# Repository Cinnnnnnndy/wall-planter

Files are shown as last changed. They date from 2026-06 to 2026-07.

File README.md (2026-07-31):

# Wall Planter — 参数化墙面种植单元

用 OpenSCAD 做的**参数化、可拼接、可 3D 打印**的单盆位墙面种植单元。对标实物:斜置花盆阵列 + 逐层滴灌 + 底部储水 + 四向堆叠拼接。面向**拓竹 P2S**(有效 256³,按 ≤240mm/轴 设计)。

## 正确形态
单元由**三个部件**组成(不是"实心块挖洞"):

1. **薄背板(panel)** — 竖直基准面,贴墙/堆叠用。
2. **前伸斜置中空杯体(cup)** — 有壁厚的圆台管,从背板向前上方斜伸(~40°);宽端开口在前上方放可拆锥形花盆,窄端平切坐在储水盒上。
3. **底部储水盒(reservoir)** — 封闭浅盒 + 前唇 + 溢流标管;杯底排水进盒,超水位经标管穿底滴到下层,底层塞橡胶塞。

## 当前文件
- **`filesv2/wall_planter_v4.scad`** — 当前基础(单元 164×183×191mm,三轴 ≤240,`Volumes=2`)。
- `filesv2/planter_v4.3mf` — 导出的可打印件(**推荐**,带 mm 单位,直接拖进拓竹 Bambu Studio / 其它切片软件)。
- `filesv2/planter_v4.stl` — 同一几何的 STL 版本(兼容老工具链)。
- `filesv2/PROMPT.md` — 几何形态描述 + 已完成/待办清单。
- `files/SPEC.md`、`files/CLAUDE.md` — 设计目标与建模迭代规范。
- `files/` 内为早期 v2 迭代(竖切开口版),供参考。

## 可调参数(在 .scad 顶部)
花盆尺寸 `pot_top_d / pot_bot_d / pot_height`、间隙 `fit_clear`、倾角 `tilt`、壁厚 `wall`、储水盒高 `res_h` / 水位 `water_h` / 前唇 `res_lip`、堆叠/横拼销径、透气孔等。

## 渲染 / 导出(OpenSCAD)
```bash
cd filesv2
# 立体预览
openscad --render -o v4_hero.png --colorscheme=Tomorrow \
  --imgsize=1000,820 --camera=82,150,150,62,0,225,720 wall_planter_v4.scad
# 导出 3MF(出图确认后,推荐)
openscad --render -o planter_v4.3mf -D 'dev=false' wall_planter_v4.scad
# 导出 STL(同一几何,兼容用)
openscad --render -o planter_v4.stl -D 'dev=false' wall_planter_v4.scad
```
开发期保持 `dev=true`(低精度快预览),导 STL 前用 `-D 'dev=false'` 提精度。

## 打印建议
建议**背板朝下平躺**打印(杯口朝上),基本免支撑;默认壁厚 3mm。

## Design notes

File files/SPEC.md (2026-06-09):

# SPEC — 我的设计目标(改模型前先读这个)

## 1. 打印机(必填,决定是否分块)
- 有效打印尺寸 X × Y × Z = **256 × 256 × 256** mm(拓竹 Bambu Lab P2S)
- 机型/喷嘴:**P2S / 0.4mm**
- 材料:待定(室内建议 PLA,室外建议 PETG/ASA)

## 2. 安装方式(三选一)
- [ ] 贴墙挂(需挂耳/锁孔或法式斜挂)
- [ ] 独立隔断(需底座脚,可能做双面花盆)
- [x] **仅堆叠**(无墙面安装件;但保留燕尾+定位销,单元间四向拼接)

## 3. 花盆形式
- 用户**自带实物锥形盆**,模块只做**承接斜插的盆座(socket)**,盆可单独取放/换盆。
  盆座按实测盆型 + 间隙做成锥台腔,不另打印花盆。

## 4. 防水要求(二选一)
- [x] **仅逐层淌水**,底层加堵塞别滴地上(当前默认)
- [ ] 真·密封储水

## 目标参数(已按用户实测盆填好)
| 参数 | 含义 | 值 |
|---|---|---|
| pot_top_d | 盆口外径(实测) | **131.2** |
| pot_bot_d | 盆底外径(实测) | **93.2** |
| pot_height | 盆高(实测) | **148** |
| pot_fit | 落盆间隙(直径上加) | **3.0(单边 1.5,已确认)** |
| pot_tilt | 杯腔倾角(度, 与水平) | **55(已确认, 更竖立贴参考图)** |
| cols | 每模块列数 | **1**(2 列=270mm 超 256,故单列) |
| rows | 每模块行数 | **1**(2 行=340mm 超 256,故单行) |
| gap_x | 花盆水平间距 | 9 |
| gap_z | 花盆行间距 | 12 |
| wall | 箱体壁厚 | 2.6 |
| reservoir | 底部储水层高 | 16 |

> 实际建模结果(已导 STL): 单元外形 = **155.4 × 191.0 × 215.5 mm**,三轴均 ≤240,P2S 单件可打;墙面靠多个单元堆叠+横拼。

## 已建模机制(planter_v2.stl, v4 斜切洁净开口, 2026-06-09)
- **开口沿花盆角度斜切**: 开口面 ⟂ 花盆轴线(=沿盆倾角), 是完整正圆、不被腔壁遮挡, 盆口平齐坐入。修复了 v3 在竖直面开圆被斜腔下壁遮挡的问题。
- **外壳=省料楔形**(非方盒): 侧剖面贴合花盆斜切, 顶/前随盆斜面、后矮竖壁、平底储水, 沿宽度拉伸→左右面平整可横拼。
- 腔体: 圆台(宽端 134.2 朝开口 / 窄端 96.2 在后下),深 150,**倾角 55°(更竖立)**,单边间隙 1.5mm(直径 +3)。
- 灌溉: 盆底排水 → 最低处储水沟(深 12)→ **溢流标管(水位 8mm)** 超水位穿底滴下层;底层标管口塞橡胶塞(⌀9)。
- 透气: 开口后上沿 3 个 ⌀5 透气孔(穿顶斜面进腔)。
- 顶后沿半圆缺口(⌀26)。
- 拼接(仅堆叠/非承重): 顶销(立在后顶斜面)+底孔、右销+左孔, 销径 7, 间隙 0.3。
- 校验: CGAL Volumes=2(单一实体, 无封闭空腔), 腔体不穿底/不穿背, 水路连通。
- 待优化: 顶面是斜的, 上下堆叠靠斜面销+侧销定位(非全平面贴合); 如需更稳的堆叠面可后续加平台接口。

## 备注
- 落盆间隙: SPEC 表里 pot_fit=2.0,但本次按 PROMPT 的「单边 1.5(直径 +3)」建模。若实测偏松/偏紧,改 `fit_clear` 即可。
- 待用户实测花盆后可调:若盆口有外翻边/卡边,可加「开口挡土前唇」防下滑;倾角可在 25–30° 间微调改变进深。
- 拼接当前用定位销(非承重燕尾);若横排需承重再换燕尾。

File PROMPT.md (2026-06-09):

# PROMPT — 单盆位墙面种植单元(喂给 Claude Code)

> 用法:把本文件放进项目根目录,在 Claude Code 里说「读 CLAUDE.md、SPEC.md、PROMPT.md,按 PROMPT 改 wall_planter_v2.scad」。
> 以现有 `wall_planter_v2.scad` 为基础**改造**,不要从零重写。每改一处按 CLAUDE.md 的闭环渲染 PNG 并查看,几何确认后导 STL。

## 目标
做一个**参数化、可 3D 打印、可堆叠/横拼**的「单盆位」墙面种植单元。
单元本身是一个**斜置的花盆托座(箱体)**,里面**斜放一个可拆卸的锥形花盆**;
顶部加水后水经盆底排水孔进入箱体底部储水层,超过水位逐层往下淌。

## 剖面机制(逐元素,来自参考剖面图)
箱体为侧剖,背板在后(贴墙侧),整体结构:

- **斜置锥形花盆腔**:箱体内主腔是一个**向后下方倾斜**的圆台(锥形)空腔,用来容纳可拆花盆。开口朝**前上方**(植物从这里长出、土朝外不易撒),盆底(窄端)落在**后下方**。倾角约 25–30°(设为参数 `pot_tilt`)。
- **植物苗**:从开口长出,叶子向前外舒展——开口必须在前面板上完整露出(正圆/椭圆开口)。
- **土壤层**:花盆内的种植土,占据锥形腔大部分。
- **透气孔**:箱体**上部侧壁/背壁**靠近盆口根部区域开若干小孔,给根系透气。位置在开口上沿一圈。
- **排水孔**:花盆**最低点(后下方盆底)**有孔,水向下穿过箱体进入底部储水层。
- **储水层**:箱体**最底部**的浅腔,承接排水孔下来的水;侧/底有**溢流孔**,超过水位则向下一层单元淌(逐层灌溉)。
- **顶部缺口**:箱体顶后沿有一处半圆缺口(参考图可见),给上方堆叠单元的水路/盆口让位,并辅助透气。
- **底层堵塞**:最底层单元的溢流孔需可被堵塞(留一个可塞橡胶塞的孔即可,不必建塞子),避免水滴到地面。

## 硬约束
- **打印机**:拓竹 P2S,有效打印体积 256×256×256mm;实际按 **≤ 240mm/轴** 设计留余量(左前角有禁打区)。
- **单元尺寸**:因花盆较大,**单次只打 1 个盆位**(`cols=1, rows=1`)。单元三维都必须 ≤ 240mm。组墙靠物理堆叠+横拼,不在单件里做多盆。
- **安装**:仅堆叠(`仅堆叠`)。**不要**加挂墙件、不要加底座脚。只需上下/左右的**堆叠定位**(定位销+孔或浅榫),保证摞起来不滑。
- **灌溉**:逐层淌水(drip-through),**不做**密封储水。储水层只需承接+溢流到下层,允许 FDM 轻微渗水。
- **材料/壁厚**:默认壁厚 2.6mm;免支撑优先。

## 可拆花盆尺寸(托座腔体按此 + 间隙)
托座的锥形腔要能**放进**这个花盆(花盆另购或另打,本单元先做托座):
- 盆高:**148 mm**
- 上开口外径:**131.2 mm**
- 盆底外径:**93.2 mm**(上大下小的圆台)

腔体取**单边 ~1.5mm 间隙**(直径方向 +3mm):腔上口径 ≈ 134.2mm,腔底径 ≈ 96.2mm,腔深 ≈ 150mm。
OpenSCAD 用 `cylinder(h=pot_depth, d1=底径, d2=上口径)` 做圆台,**宽端(d2)在开口/前,窄端(d1)在后下**。

## 需要从 wall_planter_v2.scad 改的点
1. **花盆腔改为圆台(锥形)**:把原来直圆柱 cup 换成 `d1/d2` 圆台,宽端朝开口。新增参数:`pot_top_d=131.2`、`pot_bot_d=93.2`、`pot_height=148`、`fit_clear=1.5`。`pot_d` 用 `pot_top_d+2*fit_clear` 派生。
2. **网格降为 1×1**:`cols=1, rows=1`。校核单元 W/D/H 三维都 ≤ 240,`echo` 出来确认。
3. **保留并对齐**:前面板正圆开口(用腔上口径)、开口上沿一圈**透气孔**、盆底**排水孔**、底部**储水层 + 溢流孔**。
4. **堆叠定位**:顶/底定位销+孔保留;左右用浅榫或销做横拼定位(不需要承重燕尾,因为是堆叠)。
5. **底层堵塞孔**:溢流孔尺寸设成可塞标准橡胶塞(留参数 `plug_d`,默认 ~12mm),不建塞子本体。
6. **杯体不穿背**:沿用 `mod_d` 含 `pot_d/2*sin(pot_tilt)` 容差项的写法(见 CLAUDE.md 已知坑)。

## 验收清单(逐项渲图确认)
- [ ] 正前视图(`rz=180`):开口为完整圆台口,植物能从中长出;开口上沿有透气孔。
- [ ] 立体图:花盆腔明显向后下倾斜,盆底在后下方。
- [ ] 剖视/底视:盆底排水孔 → 底部储水层 → 溢流孔贯通。
- [ ] 背面干净,无杯体穿出。
- [ ] `echo` 的单元 W×D×H 三维均 ≤ 240mm。
- [ ] `Volumes` 为 2(单一实体)。
- [ ] 导出 STL 成功。

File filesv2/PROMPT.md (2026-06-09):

# PROMPT v2 — 单盆位墙面种植单元(修正几何形态后)

> 用法:把本文件 + wall_planter_v4.scad + CLAUDE.md + SPEC.md 放进项目根目录。
> **以 wall_planter_v4.scad 为当前基础继续改**(v3=正确形态, v4=加了封闭储水盒/前唇/横拼/透气)。每改一处按 CLAUDE.md 闭环渲图查看,过验收清单后导 STL。

## ⚠️ 最重要:整体形态(之前做成实心块挖洞是完全错的)
本单元**不是**"一个实心立方体在前面挖一个圆洞"。
正确形态由**三个独立部件拼成**,杯体是**露在外面、有壁厚的中空管**:

1. **背板(panel)**:一块**薄**竖直板(厚约 8mm),是贴墙/堆叠的基准面,占满单元的宽×高。
2. **前伸斜置中空杯体(cup)**:一个**圆台形的管**(有 ~3mm 壁厚),从背板**向前上方斜伸出来**(轴线高于水平约 40°)。
   - 它是**外圆台实体 − 内圆台空腔**得到的**管**,不是在实心块里挖的洞;杯壁外表面是可见的。
   - **宽端(开口)在前上方**,植物从这里长出、人从前上方往里看;**窄端(杯底)在后下方**,坐在储水盒上。
   - 杯底留 ~6mm 厚的**底**承托花盆,底上有**排水孔**。
3. **储水盒(reservoir)**:底部一个**浅盒**(高约 24mm),承接杯底排水;盒底有**溢流孔**通向下层(最底层塞橡胶塞)。

> 判断对错的最快方法:**侧视图**应看到「竖直背板 + 一个斜约 40° 伸出的杯子 + 底部一条横置浅盒」三段;**立体图**应看到杯子是**有壁厚的张口管**,而不是平面上一个洞。

## 剖面细节(逐元素,对应参考剖面图的红点标注)
- **植物苗**:从杯体前上方开口长出。
- **土壤层**:可拆花盆放在杯体内,占据锥形内腔。
- **透气孔**:背板上部开 1–2 个小孔(贴近杯体后上方根区),给根透气。
- **排水孔**:杯底最低点 → 穿到储水盒。
- **储水层**:底部储水盒,承水;**溢流孔**在盒底,超过水位往下层淌(逐层灌溉)。
- **顶部缺口**:背板顶沿半圆缺口,给上层让水路/透气。

## 硬约束
- 打印机 拓竹 P2S,有效 256³,按 **≤240mm/轴** 设计。当前 v3 实测 164×183×189mm,达标。
- **单盆位**(一个单元一个杯),组墙靠堆叠+横拼;**仅堆叠**,不加挂墙件/底座,只做上下定位销+孔。
- **逐层淌水**,不做密封储水。
- 壁厚默认 3mm,免支撑优先。

## 可拆花盆尺寸(杯体内腔 = 此 + 单边1.5mm间隙)
- 盆高 148mm;上口外径 131.2mm;盆底外径 93.2mm(上大下小圆台)。
- 内腔用 `cylinder(h, d1=底, d2=口)` 圆台,**宽端(d2)在开口/前上**,窄端在后下。

## v4 已完成(wall_planter_v4.scad, 新基础, 2026-06-09)
> 在 v3 正确形态上继续, 单元 164.2×183.5×191.4mm(≤240), Volumes=2, STL=planter_v4.stl。
1. ✅ 储水盒 = **开顶浅盒 + 前唇**(res_lip=7): 四壁到顶(z=res_h=26)挡水, 内立**溢流标管**(water_h=14 水位), 标管孔穿底到下层、底层塞橡胶塞(overflow_d=12)。
   ⚠️ **不要加盒盖**: 杯体是斜的, 盒盖会伸进杯下沿挡住花盆(实测过)。靠盒四壁挡水即可, 杯底(floor_t)封住杯腔与盒之间, 排水孔连通。
2. ✅ 排水孔(drain_d=7)杯内底→储水盒, 兼作储水盒透气路径(故仍 Volumes=2 而非封闭空腔)。
3. ✅ **左右横拼定位**: 右侧销 + 左侧孔(在背板厚度内, 两个高度), tile_peg_d=7。
4. ✅ **上下堆叠**: 背板顶孔 + 底销(peg_d=8), 间距加宽到 0.22/0.78。
5. ✅ **透气孔**水平穿入杯体后下根区(vent_d=6 ×2), 已剖图确认通到杯内。
6. 顶后沿半圆缺口保留。

## 还可继续(v4 待办)
- 开口前沿**挡土唇**(参数 `mouth_lip`, 当前=0 未启用): 启用后在杯口加一圈内唇防土外漏/盆下滑。
- 免支撑打印朝向核验(建议背板朝下平躺打); 储水盒盒盖是悬垂面, 平躺后变竖面即免支撑。
- 横拼/堆叠销实测配合(tile/peg 间隙 0.3, 偏紧可加大)。
- 储水盒水位 water_h 与盆底排水高度联调(确认水能浸到盆底吸水)。

## 验收清单(逐项渲图确认)
- [ ] 侧视:背板 + 斜~40°伸出杯体 + 底部浅盒,三段分明。
- [ ] 立体:杯体是有壁厚的张口管(非平面挖洞)。
- [ ] 正前/上方俯视:能看进锥形内腔,开口为圆台口。
- [ ] 杯底排水孔 → 储水盒 → 溢流孔 贯通。
- [ ] echo 的 W×D×H 三维均 ≤240mm。
- [ ] Volumes 为 2(单一实体);STL 导出成功。

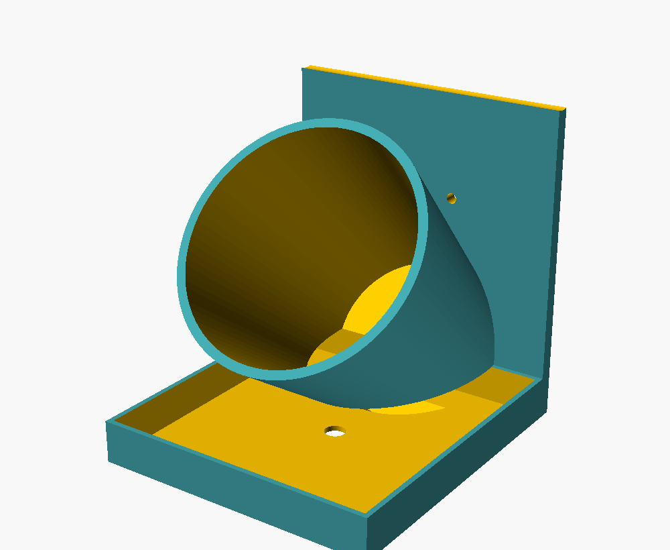
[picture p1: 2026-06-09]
filesv2/v3_hero.png

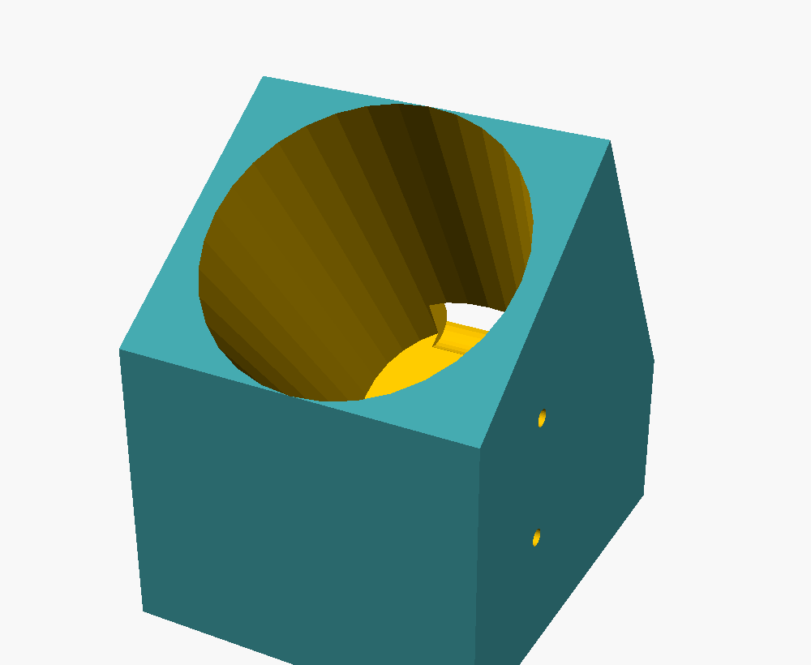
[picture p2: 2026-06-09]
files/front34.png

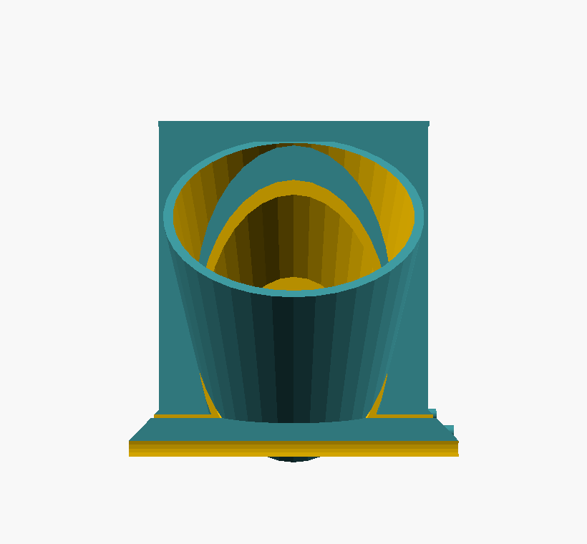
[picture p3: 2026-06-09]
filesv2/v4_vent.png

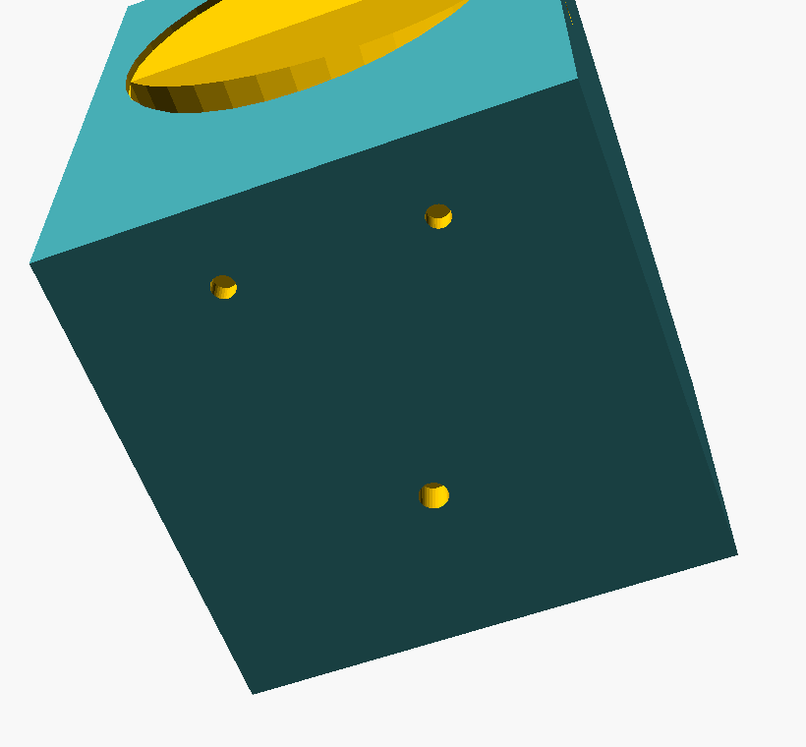
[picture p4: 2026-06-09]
files/bottom.png

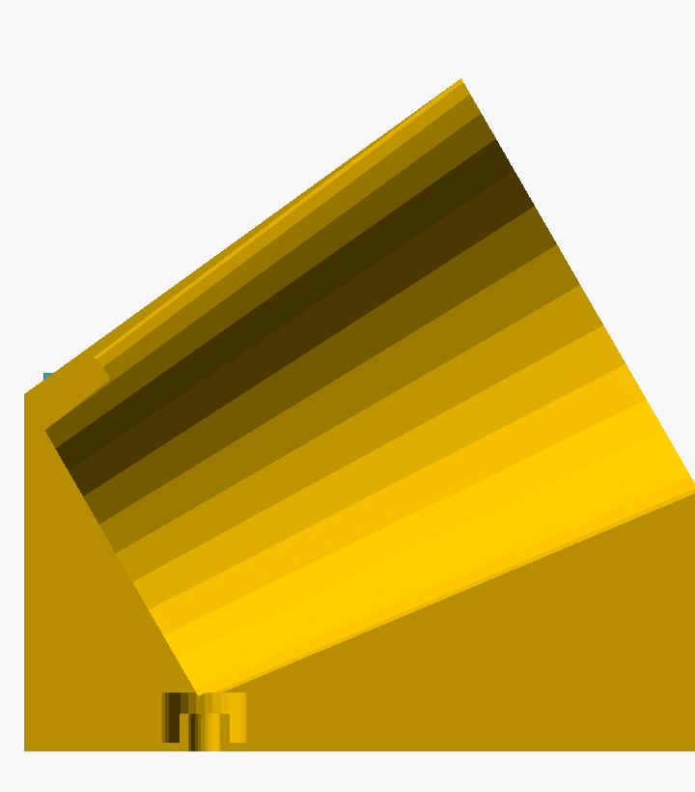
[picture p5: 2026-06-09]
files/cut.png

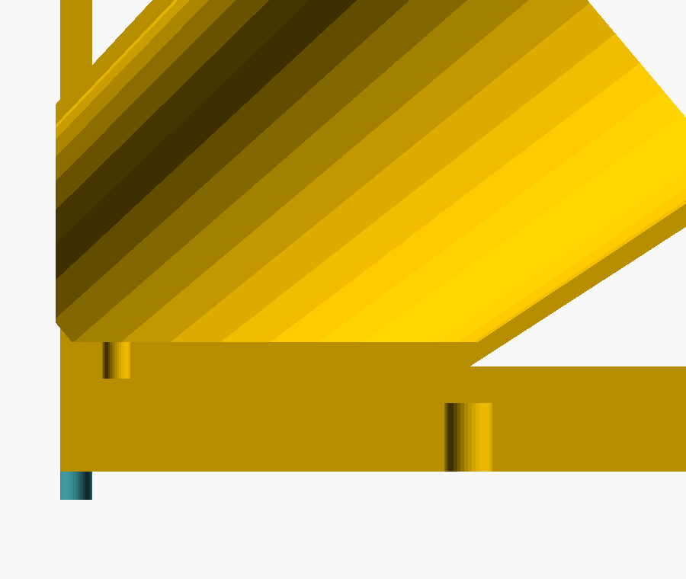
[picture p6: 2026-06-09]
filesv2/v4_cut.png

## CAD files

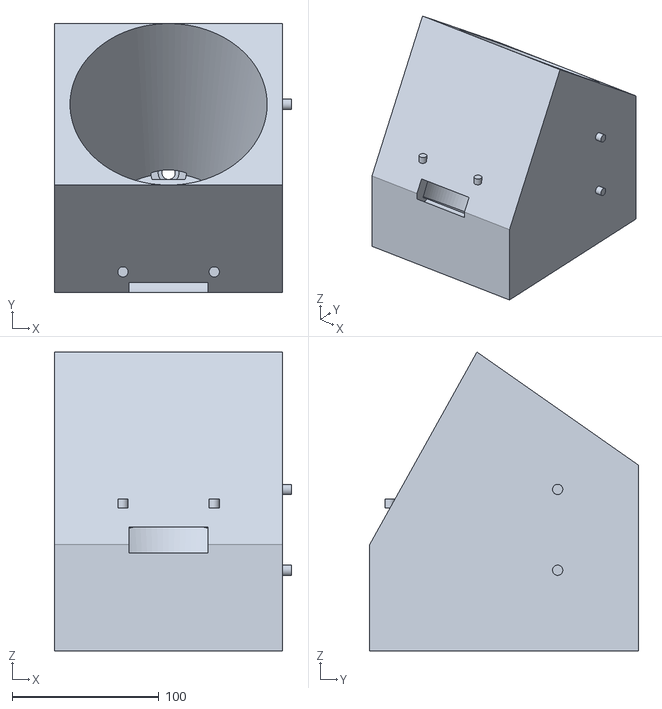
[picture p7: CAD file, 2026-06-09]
files/planter_v2.stl
161.4 x 183.0 x 203.5

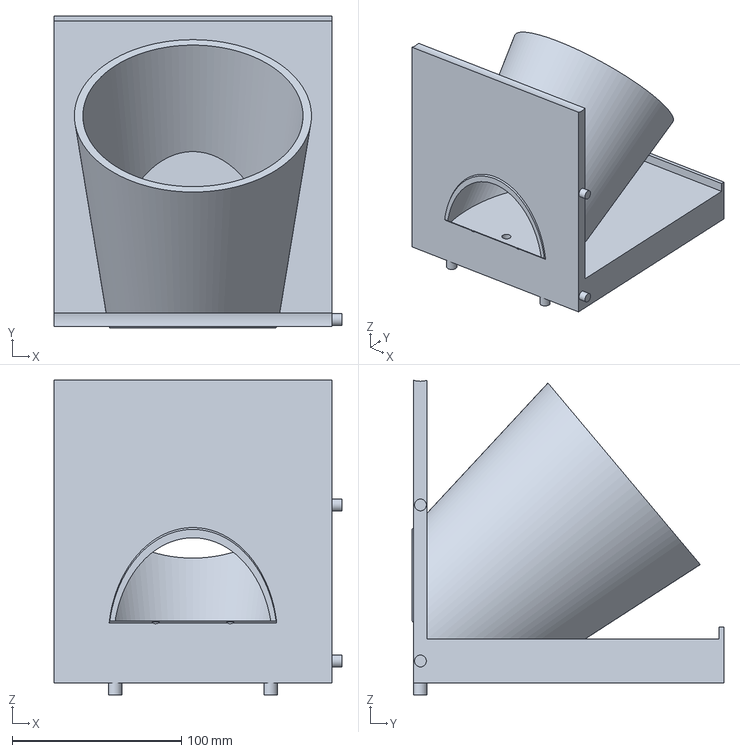
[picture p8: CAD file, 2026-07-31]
filesv2/planter_v4.3mf
170.2 x 184.5 x 186.0 mm

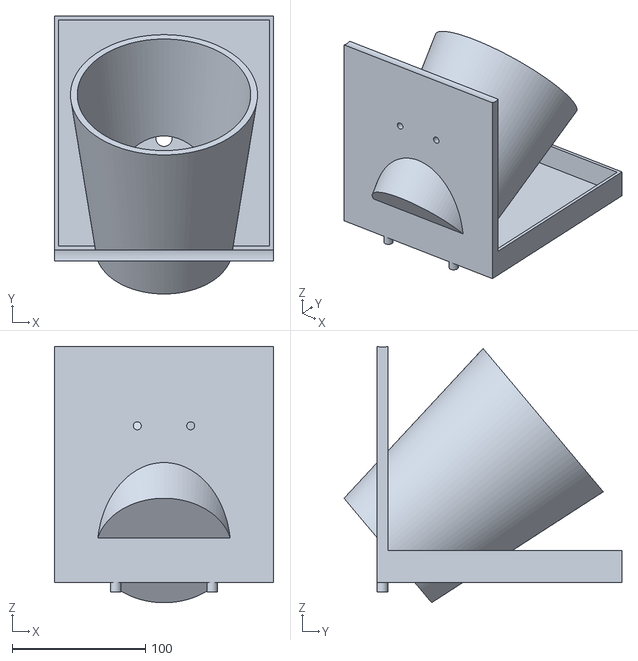
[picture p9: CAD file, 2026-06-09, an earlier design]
filesv2/planter_v3.stl
164.2 x 208.3 x 192.2

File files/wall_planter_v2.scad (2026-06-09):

// =====================================================================
//  模块化墙面种植系统 v4 — 单盆位托座 (OpenSCAD)
//  对标参考剖面图: 斜置可拆锥形花盆 + 盆底排水 + 储水沟+溢流 + 堆叠拼接
//  *省料楔形外壳 + 沿花盆角度斜切的洁净开口*
//    开口面 ⟂ 花盆轴线(沿盆倾角切), 是完整正圆、不被腔壁遮挡; 顶/前随盆斜切去废料。
//  打印机: 拓竹 P2S (256^3, 按 ≤240/轴) | 单件 1 个盆位
//  单位 mm | FDM 可打印 | 改顶部参数即可调花盆/模块尺寸
// =====================================================================

/* [可拆花盆 Pot — 实测外形, 上大下小圆台] */
pot_top_d   = 131.2;  // 花盆上开口外径(宽端, 落在开口)
pot_bot_d   = 93.2;   // 花盆底外径(窄端, 落在后下方)
pot_height  = 148;    // 花盆高
fit_clear   = 1.5;    // 腔体单边间隙(直径方向 = +2*该值)

/* [杯腔姿态 Pose] */
pot_tilt    = 55;     // 杯腔轴线与水平的夹角(越大越竖立, 开口越朝前)

/* [模块网格 Grid] 单盆位 */
cols        = 1;
gap_x       = 8;      // 盆侧净壁余量

/* [箱体 Shell] */
wall        = 2.6;    // 壁厚(0.4 喷嘴约 6 层)
back_gap    = 8;      // 杯底窄端与背板净间隙
sump_clear  = 12;     // 杯腔最低点离箱内底余量(=储水沟深, 须 > water_h)
top_clear   = 12;     // 开口最高点到顶余量

/* [灌溉 Irrigation] */
vent_d      = 5;      // 透气孔径
vent_count  = 3;      // 透气孔数
overflow_d  = 9;      // 溢流标管内径
water_h     = 8;      // 储水沟水位(标管高, < sump_clear)

/* [顶部缺口 Notch] */
notch       = true;
notch_d     = 26;

/* [堆叠定位 Interlock] 仅堆叠, 非承重 */
loc_peg_d   = 7;
loc_h       = 6;
loc_clear   = 0.3;

dev = true;
$fn = dev ? 32 : 96;

// ---- 派生尺寸 ------------------------------------------------------
cav_top_d = pot_top_d + 2*fit_clear;
cav_bot_d = pot_bot_d + 2*fit_clear;
pot_depth = pot_height + 2;
pot_d     = cav_top_d;
r_top     = cav_top_d/2;
r_bot     = cav_bot_d/2;
st        = sin(pot_tilt);
ct        = cos(pot_tilt);

mod_w     = cols*(pot_d + gap_x) + gap_x + 2*wall;

// 锥腔宽端中心 (Cy, oz0): 由"后上点离背 back_gap"和"最低点离底 sump_clear"反推
floor_in_z = wall + sump_clear;
Cy  = wall + back_gap + pot_depth*ct + r_bot*st;   // 宽端中心 Y
oz0 = floor_in_z + pot_depth*st + r_bot*ct;        // 宽端中心 Z
floor_y = Cy - pot_depth*ct;                        // 窄端中心 Y
floor_z = oz0 - pot_depth*st;                       // 窄端中心 Z

// 锥腔侧剖 rim 点 (Y,Z): F=前/宽端开口, B=后/窄端
FTy = Cy - r_top*st;  FTz = oz0 + r_top*ct;   // 前-上(开口顶)
FBy = Cy + r_top*st;  FBz = oz0 - r_top*ct;   // 前-下(开口底, 最前)
BTy = floor_y - r_bot*st;  BTz = floor_z + r_bot*ct;  // 后-上
back_face = max(0, BTy - wall);               // 后竖壁外面 Y

// 杯腔最低点(储水沟/排水)
low_y = floor_y + r_bot*st;
low_z = floor_z - r_bot*ct;

mod_d = FBy;                       // 最前 = 开口底
mod_h = FTz + top_clear;           // 最高 = 开口顶 + 余量

function cx(i) = wall + gap_x + pot_d/2 + i*(pot_d+gap_x);
// 顶斜面(C→D)在某 Y 处的外表面 Z
function slope_z(y) = (BTz+wall) + (FTz-(BTz+wall))*(y-back_face)/(FTy-back_face);

// ---- 侧剖面(楔形+斜开口, 局部坐标 x=Y, y=Z)----------------------
module side_profile() {
    polygon([
        [FBy,       0      ],   // 前-底(最前下角)
        [back_face, 0      ],   // 后-底
        [back_face, BTz+wall],  // 后竖壁顶
        [FTy,       FTz    ],   // 顶斜面到开口顶
        [FBy,       FBz    ]    // 开口斜面到开口底, 再竖直回前-底
    ]);
}
module shell() {
    multmatrix([[0,0,1,0],[1,0,0,0],[0,1,0,0],[0,0,0,1]])
        linear_extrude(mod_w) side_profile();
}

// 花盆腔: 圆台, 宽端(d1)朝开口, 窄端(d2)在后下; 开口落在斜剖面上 → 洁净正圆
module pocket(i) {
    translate([cx(i), Cy, oz0])
        rotate([90 + pot_tilt, 0, 0])
            cylinder(h = pot_depth + 1, d1 = cav_top_d, d2 = cav_bot_d);
}

// ---- 主模块 -------------------------------------------------------
module unit() {
    difference() {
        union() {
            difference() {
                shell();

                // 1) 花盆腔(在斜剖面开洁净正圆)
                for (i=[0:cols-1]) pocket(i);

                // 2) 储水沟(竖直短腔, 与锥腔底重叠 → 排水且不封闭)
                translate([cx(0), low_y, wall])
                    cylinder(h = low_z + 2 - wall, d = overflow_d + 2*wall + 10);

                // 3) 透气孔(开口上沿后方, 竖直穿顶斜面进腔)
                for (i=[0:cols-1], k=[0:vent_count-1])
                    translate([cx(i) - pot_d/4 + k*(pot_d/4), FTy - 16, mod_h + 1])
                        cylinder(h = mod_h + 1 - (slope_z(FTy-16) - 8), d = vent_d);

                // 4) 顶后沿半圆缺口
                if (notch)
                    translate([mod_w/2, back_face + notch_d*0.45, BTz + wall])
                        rotate([0,90,0])
                            cylinder(h = pot_d*0.4, d = notch_d, center = true);

                // 5) 堆叠定位孔: 底面 + 左侧
                for (sx=[mod_w*0.3, mod_w*0.7])
                    translate([sx, low_y, -0.01])
                        cylinder(h = loc_h + 0.5, d = loc_peg_d + loc_clear);
                for (sz=[55, 110])
                    translate([-0.5, Cy, sz])
                        rotate([0,90,0]) cylinder(h = loc_h + 1, d = loc_peg_d + loc_clear);
            }

            // 6) 溢流标管(立在储水沟最低处, 顶=水位)
            translate([cx(0), low_y, wall - 0.01])
                cylinder(h = water_h, d = overflow_d + 2*wall);

            // 7) 堆叠定位销: 后顶斜面 + 右侧(销立在顶斜面上, 与上层底孔配合)
            for (sx=[mod_w*0.3, mod_w*0.7])
                translate([sx, back_face + 14, slope_z(back_face + 14) - 0.01])
                    cylinder(h = loc_h, d = loc_peg_d);
            for (sz=[55, 110])
                translate([mod_w - 0.01, Cy, sz])
                    rotate([0,90,0]) cylinder(h = loc_h, d = loc_peg_d);
        }

        // 8) 标管内孔贯穿到底(储水沟 → 下层; 底层塞橡胶塞)
        translate([cx(0), low_y, -0.5])
            cylinder(h = water_h + wall + 1, d = overflow_d);
    }
}

unit();
echo(str("模块外形 W x D x H = ", mod_w, " x ", mod_d, " x ", mod_h, " mm  (限 240)"));
echo(str("开口顶 FT=(", FTy, ",", FTz, ")  开口底 FB=(", FBy, ",", FBz, ")  后壁 Y=", back_face));
echo(str("杯腔最低点 Z = ", low_z));

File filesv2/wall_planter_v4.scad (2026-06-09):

// =====================================================================
//  墙面种植单元 v4 — 薄背板 + 前伸斜置中空杯体 + 底部"封闭"储水盒
//  基于 v3 正确形态继续: 封闭储水盒(带前唇/标管溢流) + 左右横拼定位 + 优化堆叠/透气
//  对标剖面图: 杯体=露在外的有壁厚管件(非实心挖洞)
//  拓竹P2S: 单元三维 ≤240mm | 仅堆叠 | 逐层淌水 | 可拆锥形盆
//  打印朝向建议: 背板朝下平躺, 杯口朝上, 基本免支撑。
// =====================================================================

/* [可拆花盆外形 -> 内腔按此+间隙] */
pot_top_d = 131.2;   // 盆上口外径
pot_bot_d = 93.2;    // 盆底外径
pot_height= 148;     // 盆高
fit_clear = 1.5;     // 单边间隙

/* [杯体/壁] */
tilt      = 40;      // 杯轴高于水平的角度(越大开口越朝上)
wall      = 3.0;     // 杯壁/箱壁厚
floor_t   = 6;       // 杯底厚(承盆)
mouth_ext = 18;      // 开口端外伸(确保杯口完整张开)
mouth_lip = 0;       // 开口前沿挡土唇高(0=不加; >0 在杯口加一圈内唇)

/* [背板/储水盒] */
panel_t   = 8;       // 背板厚
res_h     = 26;      // 储水盒高
res_lip   = 7;       // 储水盒前唇高(高出盒盖, 挡水/还原剖面)
side_gap  = 12;      // 杯体两侧到边距

/* [灌溉/孔] */
drain_d   = 7;       // 杯底排水孔(->储水盒, 兼作储水盒透气)
overflow_d= 12;      // 溢流标管内径(->下层, 底层塞橡胶塞)
water_h   = 14;      // 储水盒水位(标管高, < res_h-wall)
vent_d    = 6;       // 透气孔
vent_n    = 2;

/* [堆叠/横拼定位] */
peg_d     = 8;       // 上下堆叠销径
peg_clear = 0.3;
tile_peg_d= 7;       // 左右横拼销径
tile_h    = 6;       // 横拼销长

dev = true;
$fn = dev ? 40 : 96;

// ---- 派生 ----------------------------------------------------------
in_bot  = pot_bot_d + 2*fit_clear;
in_top  = pot_top_d + 2*fit_clear;
out_bot = in_bot + 2*wall;
out_top = in_top + 2*wall;
cup_len = pot_height + 4;
ay = cos(tilt); az = sin(tilt);          // 杯轴方向 (0, ay, az)

mod_w  = out_top + 2*side_gap;
cx     = mod_w/2;
base_y = panel_t;                         // 杯底(窄端)贴背板前
base_z = res_h;                           // 杯底坐储水盒顶
op_y   = base_y + cup_len*ay;             // 开口中心 Y
op_z   = base_z + cup_len*az;             // 开口中心 Z
mod_d  = op_y + (out_top/2)*az + 14;      // 前向总深
mod_h  = op_z + (out_top/2)*ay + 14;      // 总高

// 斜置圆台(从局部原点沿杯轴伸出)
module frustum(d1, d2, len) {
    rotate([-(90 - tilt), 0, 0]) cylinder(h = len, d1 = d1, d2 = d2);
}

floor_top = base_z + floor_t;            // 杯内平底高度(花盆坐此, =32)

// ---- 实体 ----------------------------------------------------------
module body() {
    union() {
        cube([mod_w, panel_t, mod_h]);                       // 背板
        cube([mod_w, mod_d, res_h]);                         // 储水盒(实块, 后掏)
        translate([0, mod_d - wall, res_h]) cube([mod_w, wall, res_lip]); // 储水盒前唇
        // 杯外管: 把倾斜窄端**平切**坐在储水盒顶(裁掉下垂的尖, 避免和水盒纠缠)
        intersection() {
            translate([cx, base_y, base_z]) frustum(out_bot, out_top, cup_len);
            translate([-1, -1, base_z - 2]) cube([mod_w + 2, mod_d + 300, mod_h + 300]);
        }
    }
}

module unit() {
    difference() {
        union() {
            difference() {
                body();

                // 1) 杯内腔: **平底**(z>=floor_top), 花盆坐平底上, 内腔一路通顶不挡盆
                intersection() {
                    translate([cx, base_y, base_z]) frustum(in_bot, in_top, cup_len + mouth_ext);
                    translate([-1, -1, floor_top]) cube([mod_w + 2, mod_d + 400, mod_h + 400]);
                }

                // 2) 储水盒内腔(封闭盒: 留四壁+盒底+盒盖; 杯已平底裁切, 盒盖在杯底下方不挡盆)
                translate([wall, panel_t, wall])
                    cube([mod_w - 2*wall, mod_d - panel_t - wall, res_h - 2*wall]);

                // 3) 杯底排水孔: 杯内底 -> 储水盒腔(兼给储水盒透气, 故全局 Volumes=2)
                translate([cx, base_y + 6, wall + 1])
                    cylinder(h = res_h + floor_t + 6, d = drain_d);

                // 4) 透气孔(背板下部水平穿入杯体后下根区)
                for (k = [0 : vent_n-1])
                    translate([cx - 22 + k*44, -0.5, res_h + 12])
                        rotate([-90, 0, 0]) cylinder(h = panel_t + 30, d = vent_d);

                // 5) 背板顶部半圆缺口
                translate([cx, panel_t/2, mod_h]) rotate([0,90,0])
                    cylinder(h = mod_w, d = 26, center=true);

                // 6) 上下堆叠: 顶面定位孔(背板顶)
                for (sx = [mod_w*0.22, mod_w*0.78])
                    translate([sx, panel_t/2, mod_h - 9]) cylinder(h = 10, d = peg_d + peg_clear);

                // 7) 左右横拼: 左侧面定位孔(背板厚度内)
                for (sz = [res_h*0.5, mod_h*0.55])
                    translate([-0.5, panel_t/2, sz])
                        rotate([0,90,0]) cylinder(h = tile_h + 1, d = tile_peg_d + peg_clear);
            }

            // 8) 溢流标管(储水盒内, 顶=水位)
            translate([cx, mod_d*0.55, wall - 0.01])
                cylinder(h = water_h, d = overflow_d + 2*wall);

            // 9) 上下堆叠: 底面定位销
            for (sx = [mod_w*0.22, mod_w*0.78])
                translate([sx, panel_t/2, -7]) cylinder(h = 8, d = peg_d);

            // 10) 左右横拼: 右侧面定位销
            for (sz = [res_h*0.5, mod_h*0.55])
                translate([mod_w - 0.01, panel_t/2, sz])
                    rotate([0,90,0]) cylinder(h = tile_h, d = tile_peg_d);
        }

        // 11) 标管内孔贯穿到底(储水盒 -> 下层; 底层塞橡胶塞)
        translate([cx, mod_d*0.55, -0.5])
            cylinder(h = water_h + wall + 1, d = overflow_d);
    }
}

unit();
echo(str("单元 W x D x H = ", mod_w, " x ", mod_d, " x ", mod_h, " mm  (需 ≤240)"));
echo(str("储水盒: 高 ", res_h, " 水位 ", water_h, " 前唇 ", res_lip));

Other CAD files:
filesv2/wall_planter_v3.scad
filesv2/planter_v4.stl

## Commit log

2026-06-09 Initial commit: parametric wall-planter module (OpenSCAD)
    Three-part form: thin backplane + hollow tilted cup + closed reservoir.
    - filesv2/wall_planter_v4.scad: current base (164x183x191mm, Volumes=2)
    - filesv2/planter_v4.stl: printable export
    - files/: earlier v2 vertical-opening iteration + SPEC/CLAUDE workflow
    [planter_v2.stl, planter_v3.stl, planter_v4.stl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]
2026-07-31 提交署名归位：commit 作者改成仓库主人，关掉 Claude 尾注
    Claude Code 云端沙箱的全局 ~/.gitconfig 写死 Claude <noreply@anthropic.com>，
    于是每条 commit 的 Author 都是 GitHub 上的 @claude 账号，贡献图上没有仓库主人的
    任何记录；commit message 末尾还固定带 Co-Authored-By / Claude-Session 两行尾注。
    · .claude/settings.json —— attribution.commit / attribution.pr 设为空串，关掉
    commit 尾注与 PR 页脚。项目级配置随仓库走，云端会话拉到仓库就自动读到，
    不依赖不持久的 ~/.claude/settings.json。已有配置原样保留，只做合并。
    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
2026-07-31 新增 commit-and-publish skill：提交推送与 Pages 发布的固定走法
    把两件会静默出错的事做成脚本，不再靠事后肉眼检查：
    · scripts/commit-push.sh —— 提交前确认身份、剥掉 Claude 尾注、关掉签名，
    提交后复核 HEAD 的 author（不对就 amend --reset-author 重来），
    推送按 2/4/8/16 秒退避重试。两处踩过的坑写进了脚本：暂存路径逐个 add
    （pathspec 不存在时 git add 会整条失败、静默跳过全部改动），以及从 $0 的
    位置反解仓库根（按 cwd 取会静默作用到别的仓库上）。
    · scripts/pages-status.sh —— 判定 Pages 处于四种状态中的哪一种，
    决定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
2026-07-31 导出 v4 的 3MF 版本：filesv2/planter_v4.3mf
    · 切片软件(拓竹 Bambu Studio 等)对 3MF 的支持比 STL 完整：文件里
    带 unit="millimeter" 声明,导入不会出现单位猜错、模型缩成 1/25.4
    的情况;后续要挂打印参数/多色也是 3MF 才装得下。
    · 由 wall_planter_v4.scad 用 -D 'dev=false' 全精度($fn=96)重新导出,
    不是拿 STL 转的。包围盒与 planter_v4.stl 完全一致
    (X 0..170.190 / Y -1..183.498 / Z -7..179.039),几何是同一份。
    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
    [planter_v4.3mf]
